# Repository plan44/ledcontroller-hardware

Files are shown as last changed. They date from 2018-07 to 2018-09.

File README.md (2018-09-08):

LED controller + Connector
==========================
This repository contains KiCAD schematics and layouts for two PCBs:

The **LED controller** was built to integrate:

- 5V data outputs up to 3 WS281x individually addressable LED chains
- one PWM power output for dimming up to 80W of up to 24V LED strips
- two analog inputs (0..3.3V) for external sensors
- Ethernet connectivity

The **connector board** was designed to easily connect 7 60LED/m WS2813 LED strips to form LED display modules of 7x72 pixels each. The same board can be used on both ends of the display module, it just needs to be flipped at the far end.

The controller is based on [onion.io's Omega2S](https://onion.io/omega2s) MT7688 MIPS SoC module. It is meant to run [OpenWrt](https://openwrt.org), and there is a [custom build based on OpenWrt 18.06](https://github.com/plan44/plan44-feed/tree/master/leth-config) available which includes the [p44-ledchain kernel module](https://github.com/plan44/plan44-feed/tree/master/p44-ledchain), a small webserver and a [daemon app](https://github.com/plan44/lethd) to create scrolling texts and other effects with the LED matrix.

--
First test with RGB LED matrix and single color 80W LED strip PWM dimmer:

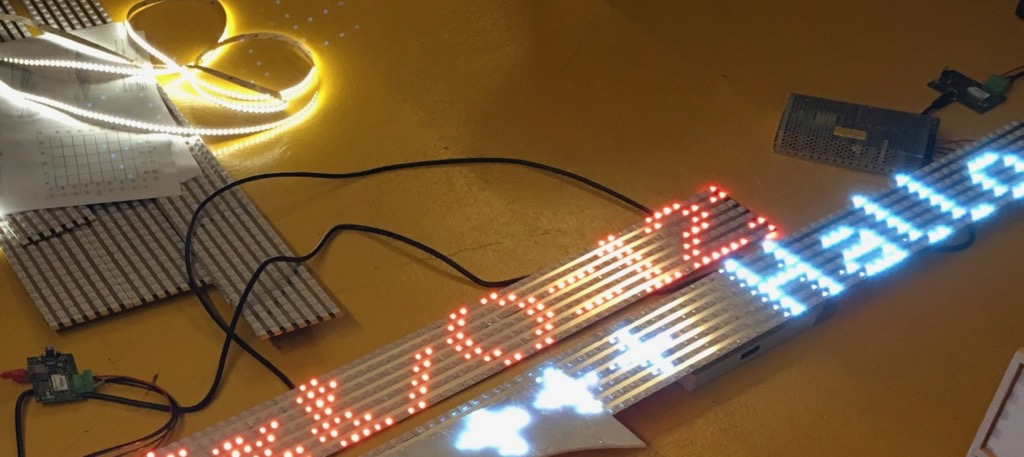
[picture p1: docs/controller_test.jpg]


--
[short video](docs/modules_test.m4v) showing scrolling text tests with multiple controllers and 7*72 LED matrix modules

--
LED Connector close up:

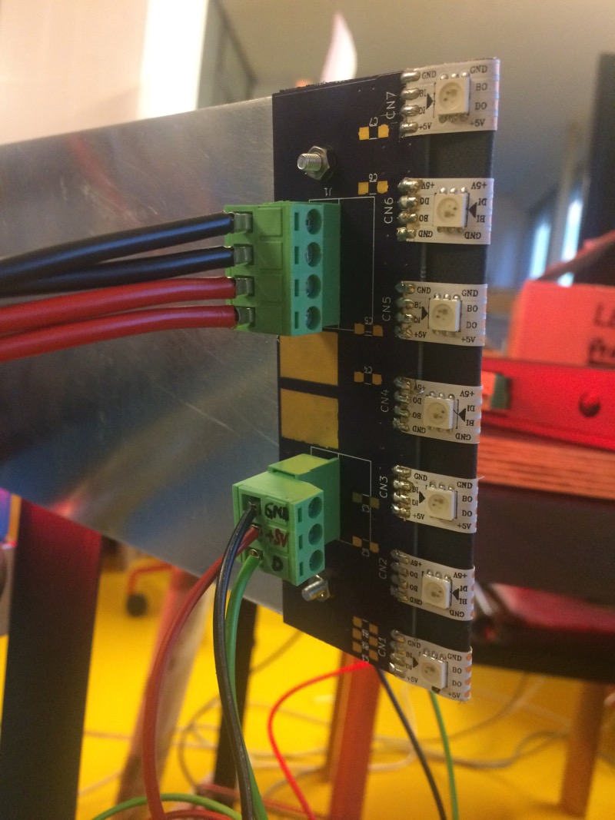
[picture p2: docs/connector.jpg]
LED connector close up


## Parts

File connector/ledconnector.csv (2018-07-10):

Reference | Value | Footprint | Datasheet | Field4 | Field5
CN1 | WS2813-CONN-IN | plan44:WS2813-CONN
CN2 | WS2813-CONN-OUT | plan44:WS2813-CONN
CN3 | WS2813-CONN-IN | plan44:WS2813-CONN
CN4 | WS2813-CONN-OUT | plan44:WS2813-CONN
CN5 | WS2813-CONN-IN | plan44:WS2813-CONN
CN6 | WS2813-CONN-OUT | plan44:WS2813-CONN
CN7 | WS2813-CONN-IN | plan44:WS2813-CONN
C1 | 100nF | Capacitors_SMD:C_1206_HandSoldering
C2 | 100nF | Capacitors_SMD:C_1206_HandSoldering
C3 | 100nF | Capacitors_SMD:C_1206_HandSoldering
CN11 | WS2813-CONN-OUT | plan44:WS2813-CONN
CN12 | WS2813-CONN-IN | plan44:WS2813-CONN
CN13 | WS2813-CONN-OUT | plan44:WS2813-CONN
CN14 | WS2813-CONN-IN | plan44:WS2813-CONN
CN15 | WS2813-CONN-OUT | plan44:WS2813-CONN
CN16 | WS2813-CONN-IN | plan44:WS2813-CONN
CN17 | WS2813-CONN-OUT | plan44:WS2813-CONN
J2 | STELVIO-3P-508 | plan44:STELVIO-3P-508-S |  | distrelec.ch | 300-43-015
R1 | 10k | Resistors_SMD:R_1206_HandSoldering
R2 | 10k | Resistors_SMD:R_1206_HandSoldering
C4 | 100nF | Capacitors_SMD:C_1206_HandSoldering
C5 | 100nF | Capacitors_SMD:C_1206_HandSoldering
C6 | 100nF | Capacitors_SMD:C_1206_HandSoldering
C7 | 100nF | Capacitors_SMD:C_1206_HandSoldering
J4 | CONN_01X02 | plan44:LETH-PowerPad
J3 | CONN_01X02 | plan44:LETH-PowerPad
J1 | STELVIO-4P-508 | plan44:STELVIO-4P-508-S |  | distrelec.ch | 300-43-016
MH1 | CONN_01X01 | Mounting_Holes:MountingHole_3.2mm_M3_DIN965_Pad
MH2 | CONN_01X01 | Mounting_Holes:MountingHole_3.2mm_M3_DIN965_Pad

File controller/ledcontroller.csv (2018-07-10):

Reference | Value | Footprint | Datasheet | Field4 | Field5
U2 | Recom_R785.0-0.5 | plan44:Recom-R78Cxx |  | distrelec.ch | 169-07-681
C6 | 100nF | Capacitors_SMD:C_1206_HandSoldering
C3 | 100nF | Capacitors_SMD:C_1206_HandSoldering
C8 | 1uF | Capacitors_SMD:C_1206_HandSoldering
R5 | 49.9_1% | Resistors_SMD:R_0805_HandSoldering
R6 | 49.9_1% | Resistors_SMD:R_0805_HandSoldering
R7 | 49.9_1% | Resistors_SMD:R_0805_HandSoldering
R8 | 49.9_1% | Resistors_SMD:R_0805_HandSoldering
C1 | 100nF | Capacitors_SMD:C_1206_HandSoldering
C2 | 100nF | Capacitors_SMD:C_1206_HandSoldering
R10 | 1k | Resistors_SMD:R_1206_HandSoldering |  | distrelec.ch | 300-56-913
R11 | 1k | Resistors_SMD:R_1206_HandSoldering
MH1 | CONN_01X01 | Mounting_Holes:MountingHole_3.2mm_M3_DIN965_Pad
MH2 | CONN_01X01 | Mounting_Holes:MountingHole_3.2mm_M3_DIN965_Pad
C7 | 22uF 25V | Capacitors_ThroughHole:CP_Radial_D7.5mm_P2.50mm |  | distrelec.ch | 167-00-355
MH3 | CONN_01X01 | Mounting_Holes:MountingHole_3.2mm_M3_DIN965_Pad
MH4 | CONN_01X01 | Mounting_Holes:MountingHole_3.2mm_M3_DIN965_Pad
C10 | 100nF | Capacitors_SMD:C_1206_HandSoldering
D1 | Everlight 339-1SURSYGW/S530-A3 | LEDs:LED_D5.0mm-3 |  | distrelec.ch | 175-00-713
R1 | 470 | Resistors_SMD:R_1206_HandSoldering
R2 | 1k2 | Resistors_SMD:R_1206_HandSoldering |  | distrelec.ch | 300-56-921
SW1 | Omron PB | Buttons_Switches_ThroughHole:SW_PUSH_6mm_h4.3mm |  | distrelec.ch | 110-88-847
R9 | 10k | Resistors_SMD:R_1206_HandSoldering
P1 | FDI_Cable | Pin_Headers:Pin_Header_Straight_1x06_Pitch2.54mm
C17 | 100nF | Capacitors_SMD:C_1206_HandSoldering
C16 | 10uF | Capacitors_ThroughHole:CP_Radial_D7.5mm_P2.50mm
U1 | ONION-OMEGA2S | plan44:ONION-OMEGA2S |  | onion.io | Omega2S
Q1 | IRLU2905PBF | TO_SOT_Packages_SMD:TO-252-2
J3 | STELVIO-2P-508 | plan44:STELVIO-2P-508 |  | distrelec.ch | 300-43-025
J4 | STELVIO-2P-508 | plan44:STELVIO-2P-508 |  | distrelec.ch | 300-43-025
J1 | USB_A | Connect:USB_A |  | distrelec.ch | 300-49-711
D4 | DO-214AA | Diodes_SMD:D_SMB_Handsoldering |  | distrelec.ch | 170-13-564
D3 | DO-214AA | Diodes_SMD:D_SMB_Handsoldering
D2 | DO-214AA | Diodes_SMD:D_SMB_Handsoldering
R3 | 47R | Resistors_SMD:R_1206_HandSoldering |  | distrelec.ch | 300-56-961
R4 | 47R | Resistors_SMD:R_1206_HandSoldering
U4 | 74AHCT125 | SMD_Packages:SOIC-14_N |  | distrelec.ch | 300-22-914
R12 | 100k | Resistors_SMD:R_1206_HandSoldering
P2 | CONN_01X02 | plan44:CONFIG-PAD-2P
U3 | Recom_R783.3-0.5 | plan44:Recom-R78Cxx |  | distrelec.ch | 169-07-680
C14 | 100nF | Capacitors_SMD:C_1206_HandSoldering
C13 | 10uF 50VDC | Capacitors_ThroughHole:CP_Radial_D7.5mm_P2.50mm |  | distrelec.ch | 167-00-587
C15 | 22uF 25V | Capacitors_ThroughHole:CP_Radial_D7.5mm_P2.50mm |  | distrelec.ch | 167-00-355
C12 | 100nF | Capacitors_SMD:C_1206_HandSoldering
R13 | 100k | Resistors_SMD:R_1206_HandSoldering
R14 | 100k | Resistors_SMD:R_1206_HandSoldering
R15 | 100k | Resistors_SMD:R_1206_HandSoldering
J5 | STELVIO-5P-508 | plan44:STELVIO-5P-508 |  | distrelec.ch | 300-43-017
P3 | CONN_01X02 | plan44:CONFIG-PAD-2P
J2 | Pulse-J0026D21B | plan44:PULSE-J0026D21B |  | Fundus S.Flüeler | J0026D21B
C9 | 1nF/2kV | Capacitors_SMD:C_1206_HandSoldering |  | distrelec.ch | 301-11-186
U5 | MCP3002 | SMD_Packages:SOIC-8-N |  | distrelec.ch | 300-55-987
J6 | STELVIO-4P-508 | plan44:STELVIO-4P-508
P4 | CONN_01X02 | plan44:CONFIG-PAD-2P
P5 | CONN_01X02 | plan44:CONFIG-PAD-2P
C11 | 100nF | Capacitors_SMD:C_1206_HandSoldering
C4 | 10uF 50VDC | Capacitors_ThroughHole:CP_Radial_D7.5mm_P2.50mm |  | distrelec.ch | 167-00-587

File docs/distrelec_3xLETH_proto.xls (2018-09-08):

Menge | Distrelec Artikelnummer | Ihre Referenz
48 | 300-86-868 | C1
12 | 300-56-813 | R5
12 | 300-56-915 | R12
9 | 167-00-587 | C16
9 | 170-13-564 | D2
9 | 300-56-914 | R9
6 | 167-00-355 | C15
6 | 300-43-003 | J3-b
6 | 300-43-005 | J6-b
6 | 300-43-025 | J3
6 | 300-43-027 | J6
6 | 300-56-913 | R10
6 | 300-56-961 | R3
3 | 169-07-680 | U3
3 | 171-18-672 | Q1
3 | 175-00-713 | D1
3 | 300-22-914 | U4
3 | 300-43-004 | J2-b
3 | 300-43-006 | J5-b
3 | 300-43-015 | J2
3 | 300-43-016 | J1
3 | 300-43-028 | J5
3 | 300-49-711 | J1
3 | 300-55-987 | U5
3 | 300-56-921 | R2
3 | 300-56-957 | R1
3 | 300-66-377 | C8
3 | 300-93-647 | P1
3 | 301-11-186 | C9

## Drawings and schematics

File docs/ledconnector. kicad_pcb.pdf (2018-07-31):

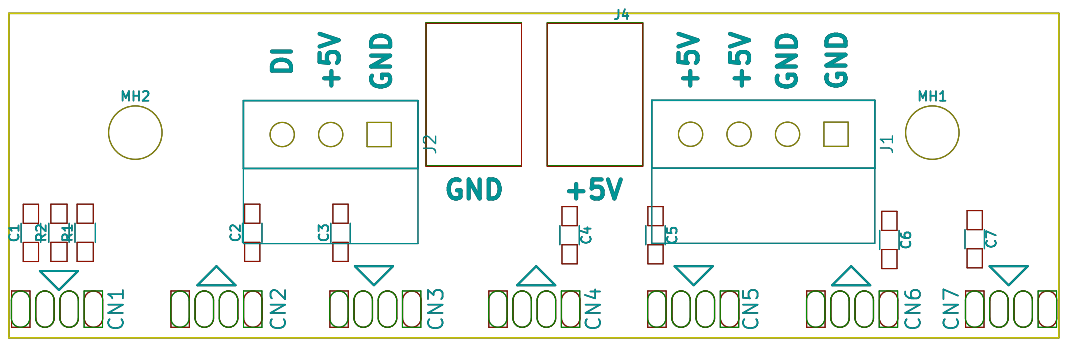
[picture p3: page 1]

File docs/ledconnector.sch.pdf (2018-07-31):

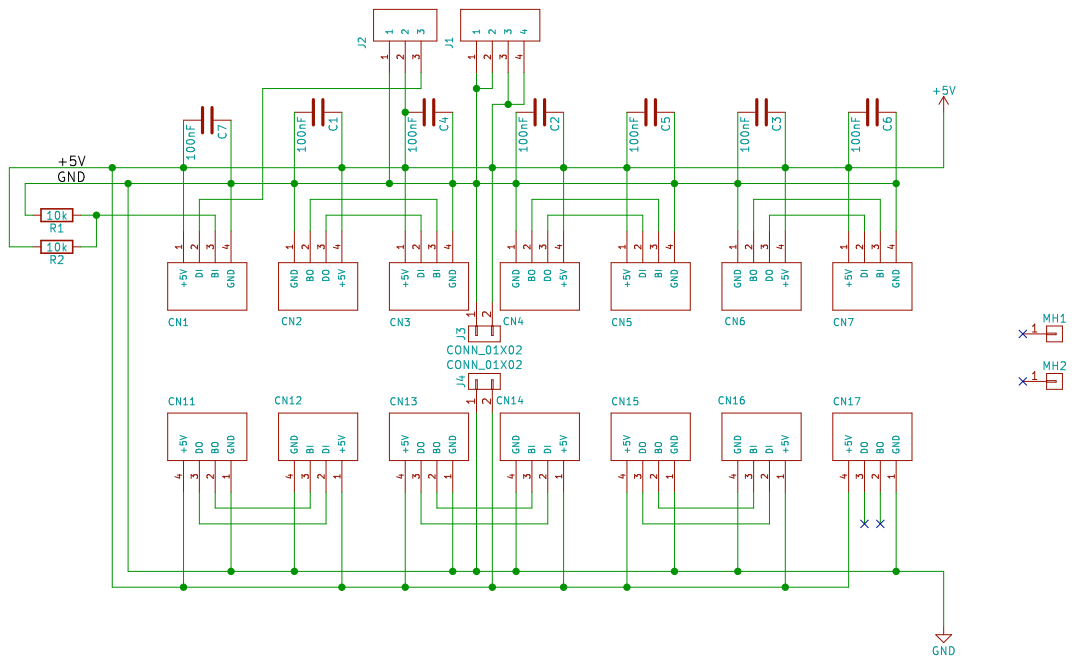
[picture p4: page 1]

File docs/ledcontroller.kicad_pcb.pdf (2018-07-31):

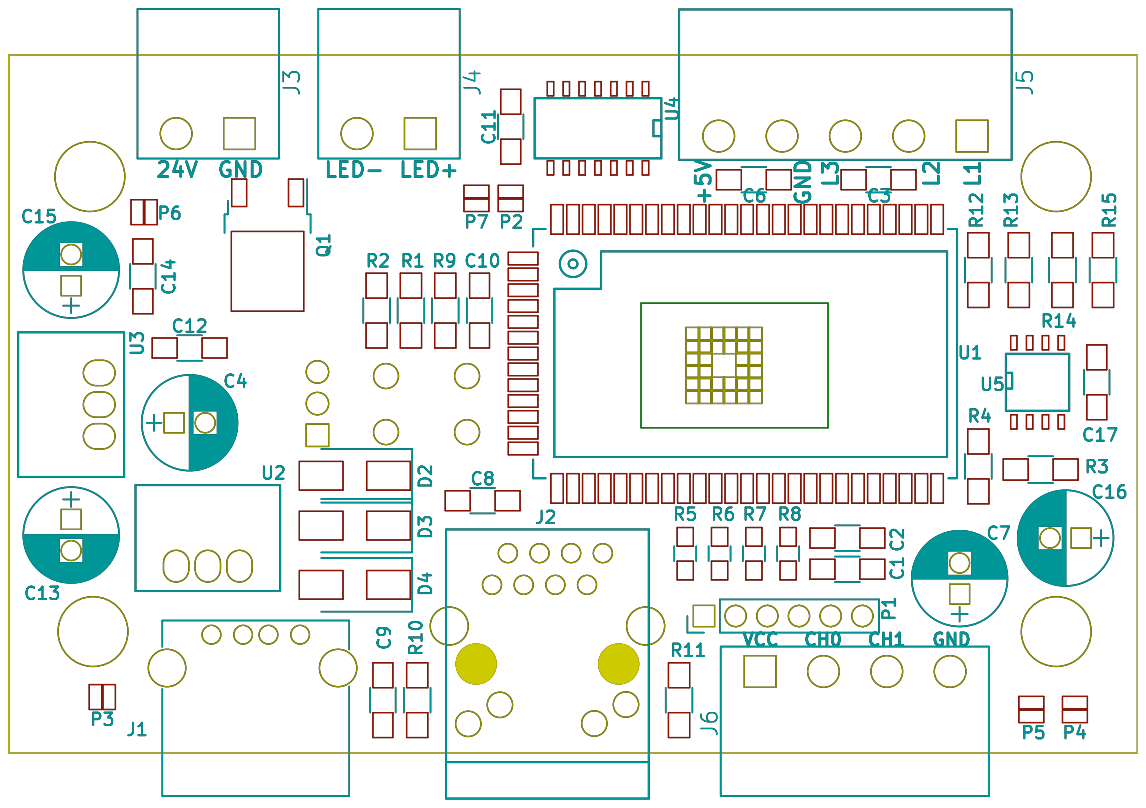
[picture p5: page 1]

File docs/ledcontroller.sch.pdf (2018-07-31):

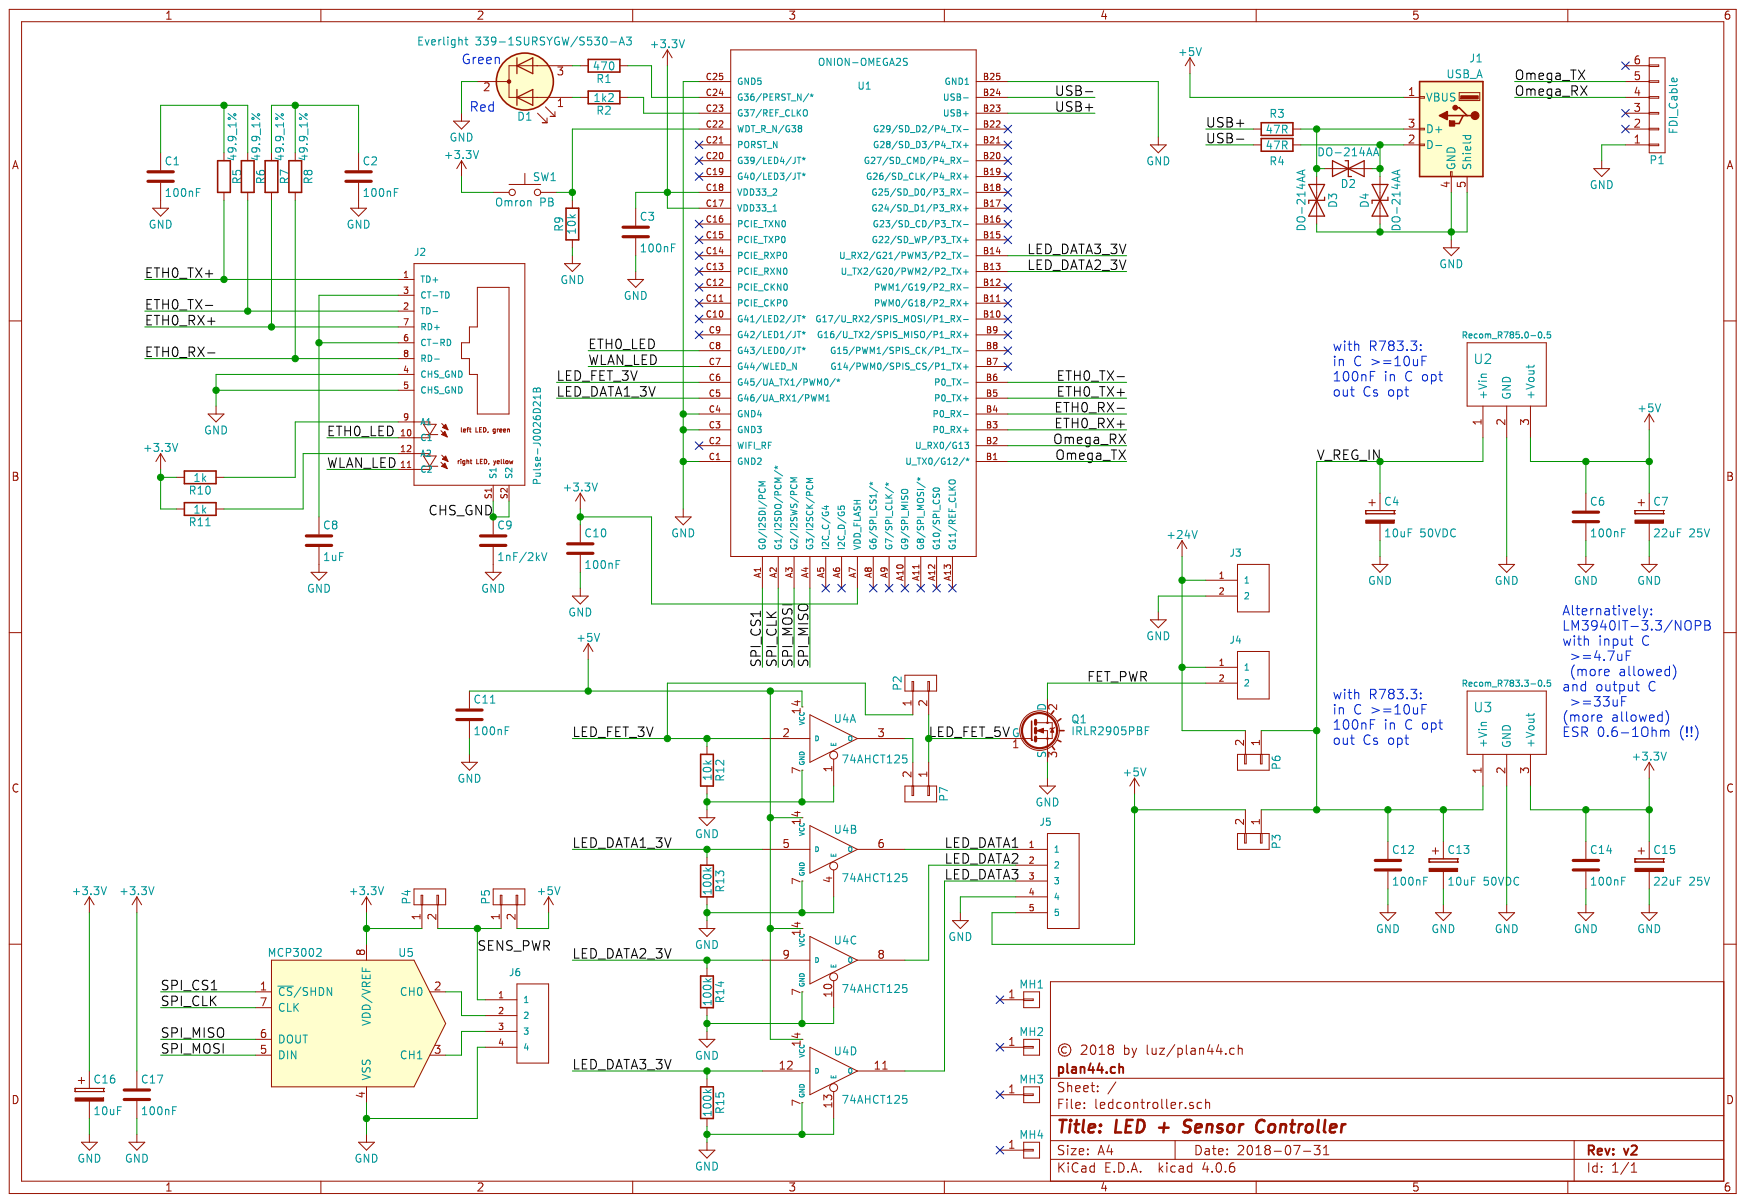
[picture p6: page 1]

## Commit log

2018-07-10 Initial commit of mostly complete schematics
    [ledcontroller.kicad_pcb, ledcontroller.sch]
2018-07-10 PCB: Basic placement and initial routing ok
    [_saved_ledcontroller.sch, ledcontroller.dsn, ledcontroller.kicad_pcb]
2018-07-10 First completely routed version including zones for Power FET
    [_saved_ledcontroller.sch, ledcontroller.kicad_pcb, ledcontroller.sch]
2018-07-10 Placed component references more nicely
    [ledcontroller.kicad_pcb]
2018-07-10 renamed folder from kicad->controller
    [ledcontroller.dsn, ledcontroller.kicad_pcb, ledcontroller.sch]
2018-07-10 Added connector PCB
    [ledconnector.kicad_pcb, ledconnector.sch]
2018-07-10 First finalized connector board, now with 4P power (30A!) and mounting holes
    [ledconnector.kicad_pcb, ledconnector.sch]
2018-07-10 BOM for first prototype order
    [distrelec_3xLETH_proto.xls, ledconnector.csv, ledcontroller.csv]
2018-07-13 Move MCP3002 SPI to GPIO 0..3 pins of Omega2 (HW SPI does not work)
    [ledcontroller.dsn, ledcontroller.kicad_pcb, ledcontroller.sch]
2018-07-28 Schematics: Q1 is SMT, we had the THT variant (IRLU vs IRLR)
    [ledcontroller.sch]
2018-07-28 Schematics: MCP1826S is deprecated, using LM3940IT instead, different (more difficult) specs for required capacitors
    [ledcontroller.sch]
2018-07-28 Updated schematics PDF
2018-07-31 ledconnector: use updated connectors from plan44 library with larger holes (and correct reference points), pinout info and LED data direction arrows on top silk layer.
    [ledconnector.kicad_pcb]
2018-07-31 ledcontroller v2: connector holes, better power selection, FET driver, silk info
    - use updated connectors from plan44 library with larger holes (and correct reference points)
    - separated 5V and 24V such that 24V FET can be used even if we also have 5V
    - swapped PWM2+3 output lines to match connector signal name/order.
    - pulldown for FET driver changed to 10k (100k was apparently too weak)
    - pinout info for connectors on silk screen
    [ledcontroller.kicad_pcb, ledcontroller.sch]
2018-08-07 fix swapped +24V/GND silk screen text for base light LED power input connector
    [ledcontroller.kicad_pcb]
2018-08-19 Removed paste mask layer for THT components and config pads, made via drill 0.3mm as recommended by PCB-POOL
    [ledcontroller.kicad_pcb]
2018-09-08 README, LICENSE (CC BY-SA 4.0), some more docs
    [distrelec_3xLETH_proto.xls]
